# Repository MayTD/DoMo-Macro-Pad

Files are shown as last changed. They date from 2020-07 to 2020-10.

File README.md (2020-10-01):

# DoMo Macro Pad
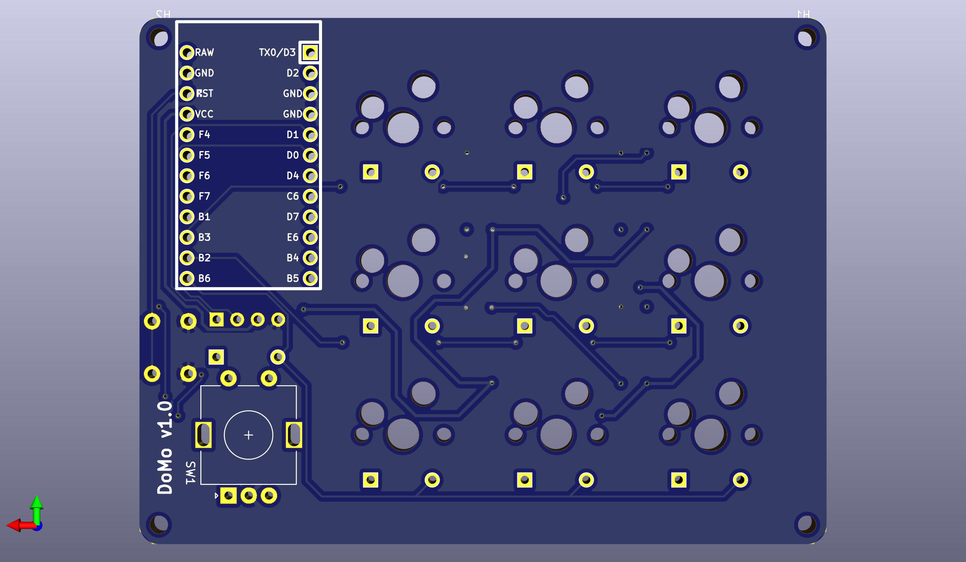
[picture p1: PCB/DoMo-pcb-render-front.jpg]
PCB render

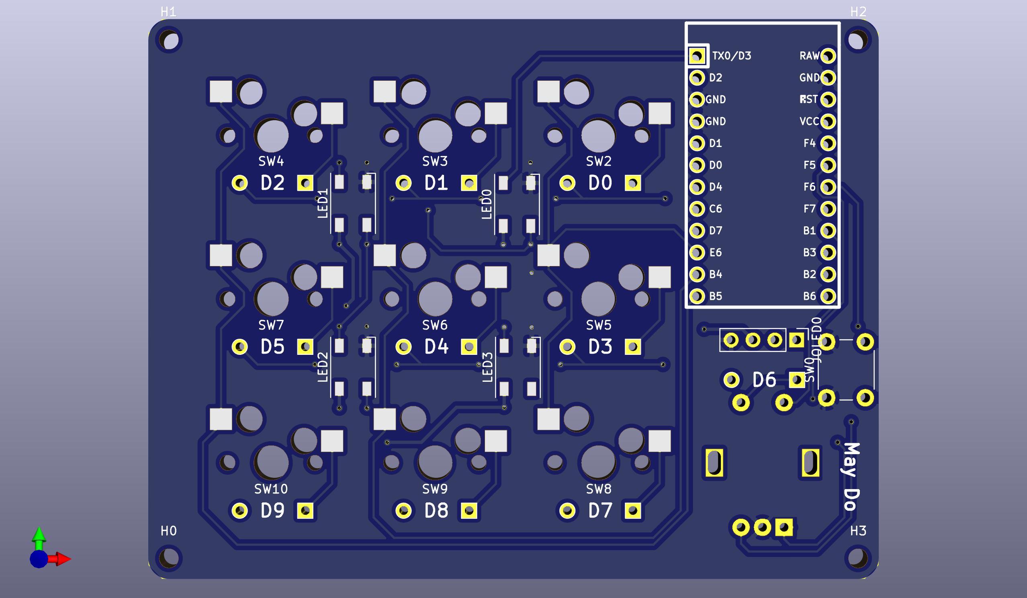
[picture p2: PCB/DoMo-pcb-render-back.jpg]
PCB render


DoMo is a 3x3 macro pad with a rotary encoder and OLED display. It's a straightforward design with a straightforward idea. I originally designed this for myself to provide quick access to most commonly used keys especially for programming. That means the top priority were to include shortcuts for copy and paste! However this can also be used just as any other macro pads for media controls to help improve workflow.

QMK: https://github.com/MayTD/qmk_firmware/tree/master/keyboards/domo

## Features

- QMK Firmware Support
- MX Hot Swap
- OLED Screen
- Rotary Encoder
- LEDS

## Assembly 
Note that source files only covers the PCB. Components must be assembled in order for the board to be functional or completed.
| Number of Parts | Component | Description |
| --- | --- | --- |
| 1 | USB Cable  | Depends on choice of microcontrollers |
| 1 | Pro Micro or Equivalent | Microcontroller that features USB connectivity on-board |
| 1 | Reset Switch | Switch to enter bootloader mode |
| 10 | Diodes | standard switching signal diode | 
| 9 | Kailh MX Sockets | Hot Swapping Sockets which can support MX switches |
| 9 | MX switches | PCB supports PCB Mounted switches | 
| 1 | Rotary Encoder | EC11, 5Pin, 6mm |
| 9 | Keycaps | Any keycaps of choice |
| 1 | Bottom Plate | PCB includes 4 mounting holes that could fit M2 screws | 
| 4 | LEDS | Individual WS2812B 5050 RGB LEDs|
| 4 | 1x4 Connector | 4 pin male header|
| 1 | OLED Display | 0.91 128×32 Display Module|

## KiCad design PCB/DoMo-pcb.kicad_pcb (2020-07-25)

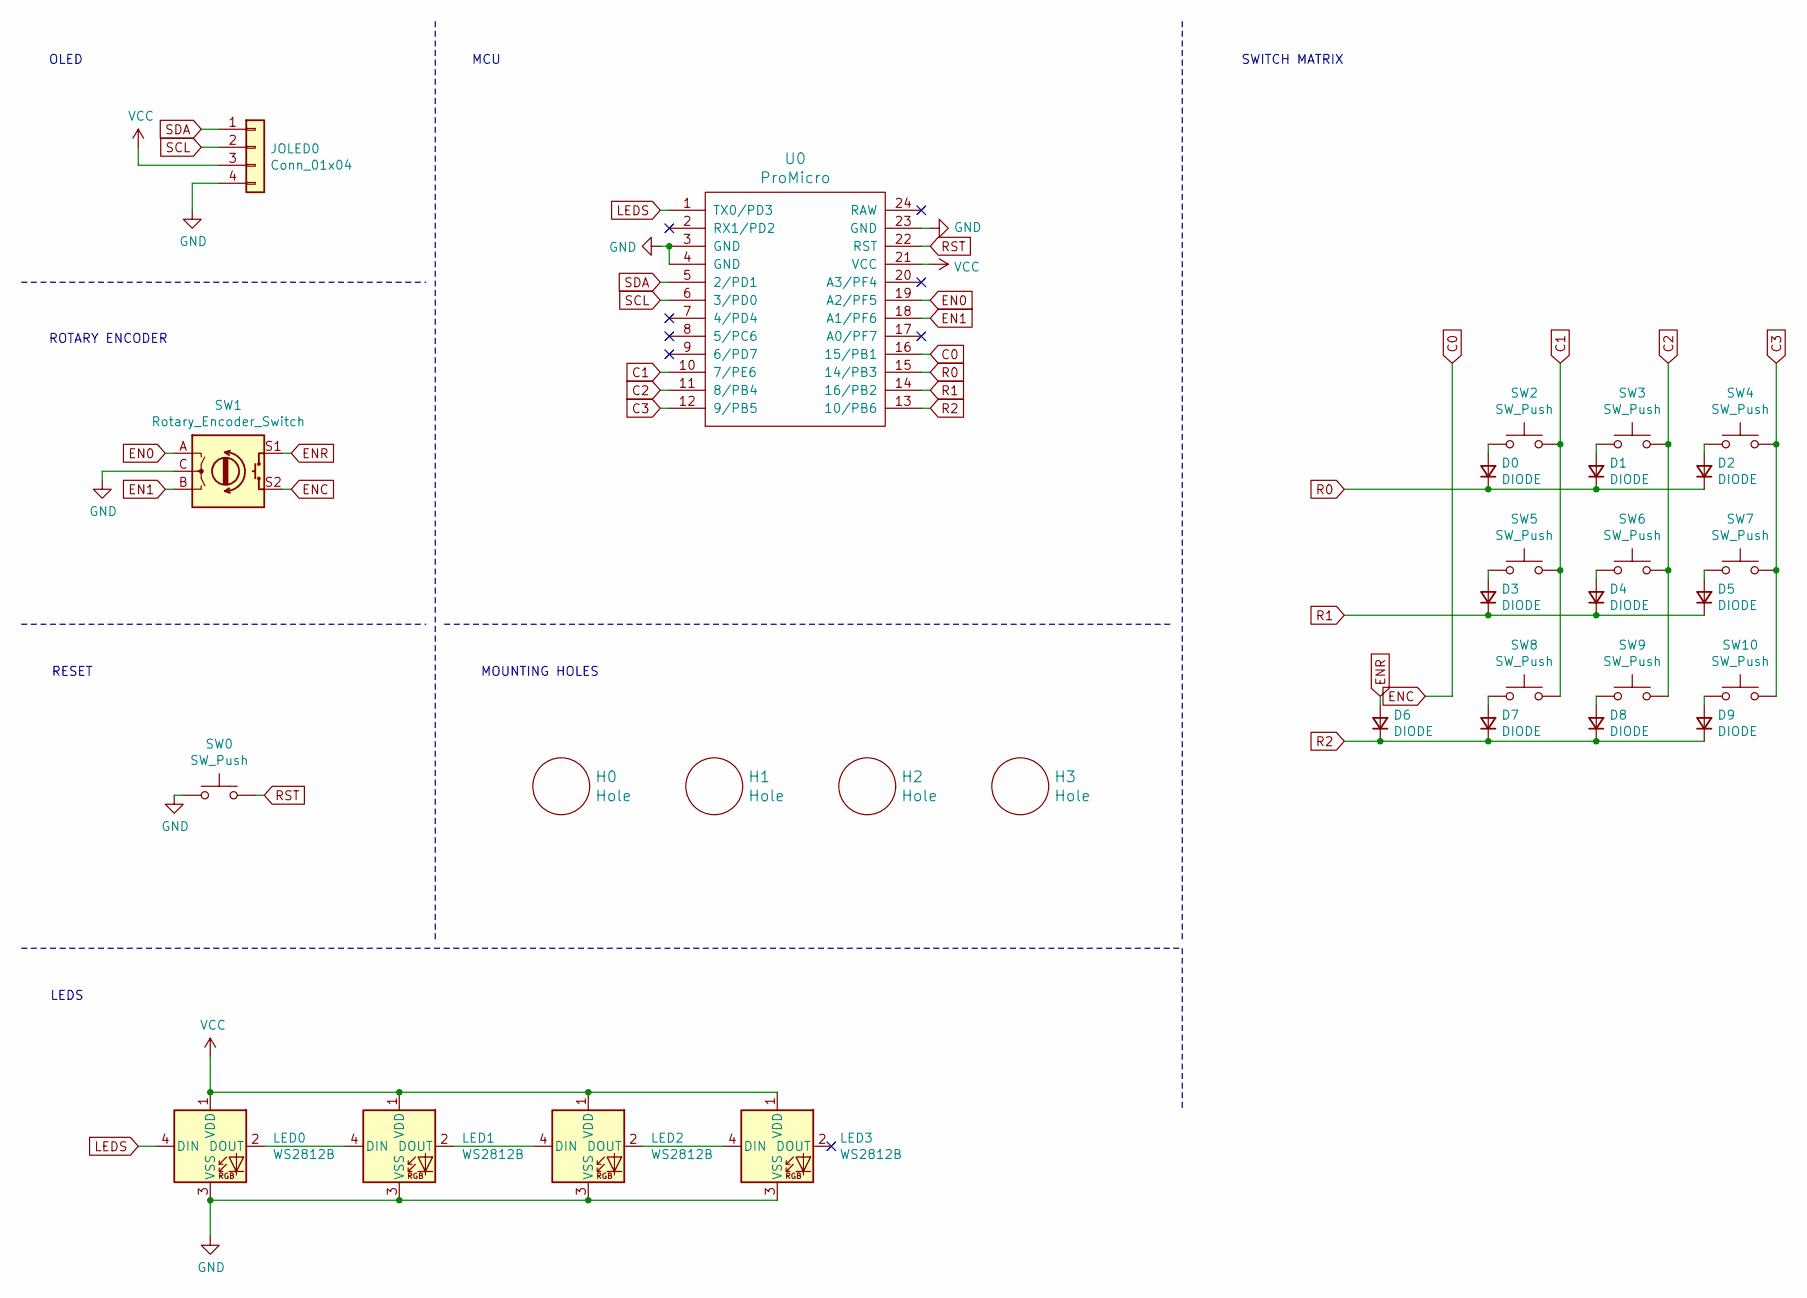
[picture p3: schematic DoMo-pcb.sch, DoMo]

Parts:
D0, D1, D2, D3, D4, D5, D6, D7, D8, D9: DIODE; MD_Diode
H0, H1, H2, H3: Hole; MountingHole_2.2mm_M2
JOLED0: Conn_01x04; Pin_Header_Straight_1x04_Pitch2.54mm
LED0, LED1, LED2, LED3: WS2812B; LED_WS2812B-PLCC4
SW0: SW_Push; SW_PUSH_6mm
SW1: Rotary_Encoder_Switch; RotaryEncoder_Alps_EC11E-Switch_Vertical_H20mm
SW2, SW3, SW4, SW5, SW6, SW7, SW8, SW9, SW10: SW_Push; MXOnly-1U-Hotswap
U0: ProMicro; ArduinoProMicro

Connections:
C0: SW1.S2, U0.16 (15/PB1)
C1: SW2.2, SW5.2, SW8.2, U0.10 (7/PE6)
C2: SW3.2, SW6.2, SW9.2, U0.11 (8/PB4)
C3: SW4.2, SW7.2, SW10.2, U0.12 (9/PB5)
EN0: SW1.A, U0.19 (A2/PF5)
EN1: SW1.B, U0.18 (A1/PF6)
ENR: D6.2 (A), SW1.S1
GND: JOLED0.4, LED0.3 (VSS), LED1.3 (VSS), LED2.3 (VSS), LED3.3 (VSS), SW0.1, SW1.C, U0.3 (GND), U0.4 (GND), U0.23 (GND)
LEDS: LED0.4 (DIN), U0.1 (TX0/PD3)
unnamed: D0.2 (A), SW2.1
unnamed: D1.2 (A), SW3.1
unnamed: D2.2 (A), SW4.1
unnamed: D3.2 (A), SW5.1
unnamed: D4.2 (A), SW6.1
unnamed: D5.2 (A), SW7.1
unnamed: D7.2 (A), SW8.1
unnamed: D8.2 (A), SW9.1
unnamed: D9.2 (A), SW10.1
unnamed: LED0.2 (DOUT), LED1.4 (DIN)
unnamed: LED1.2 (DOUT), LED2.4 (DIN)
unnamed: LED2.2 (DOUT), LED3.4 (DIN)
R0: D0.1 (K), D1.1 (K), D2.1 (K), U0.15 (14/PB3)
R1: D3.1 (K), D4.1 (K), D5.1 (K), U0.14 (16/PB2)
R2: D6.1 (K), D7.1 (K), D8.1 (K), D9.1 (K), U0.13 (10/PB6)
RST: SW0.2, U0.22 (RST)
SCL: JOLED0.2, U0.6 (3/PD0)
SDA: JOLED0.1, U0.5 (2/PD1)
VCC: JOLED0.3, LED0.1 (VDD), LED1.1 (VDD), LED2.1 (VDD), LED3.1 (VDD), U0.21 (VCC)

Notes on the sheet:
OLED
LEDS
ROTARY ENCODER
RESET
SWITCH MATRIX
MCU
MOUNTING HOLES

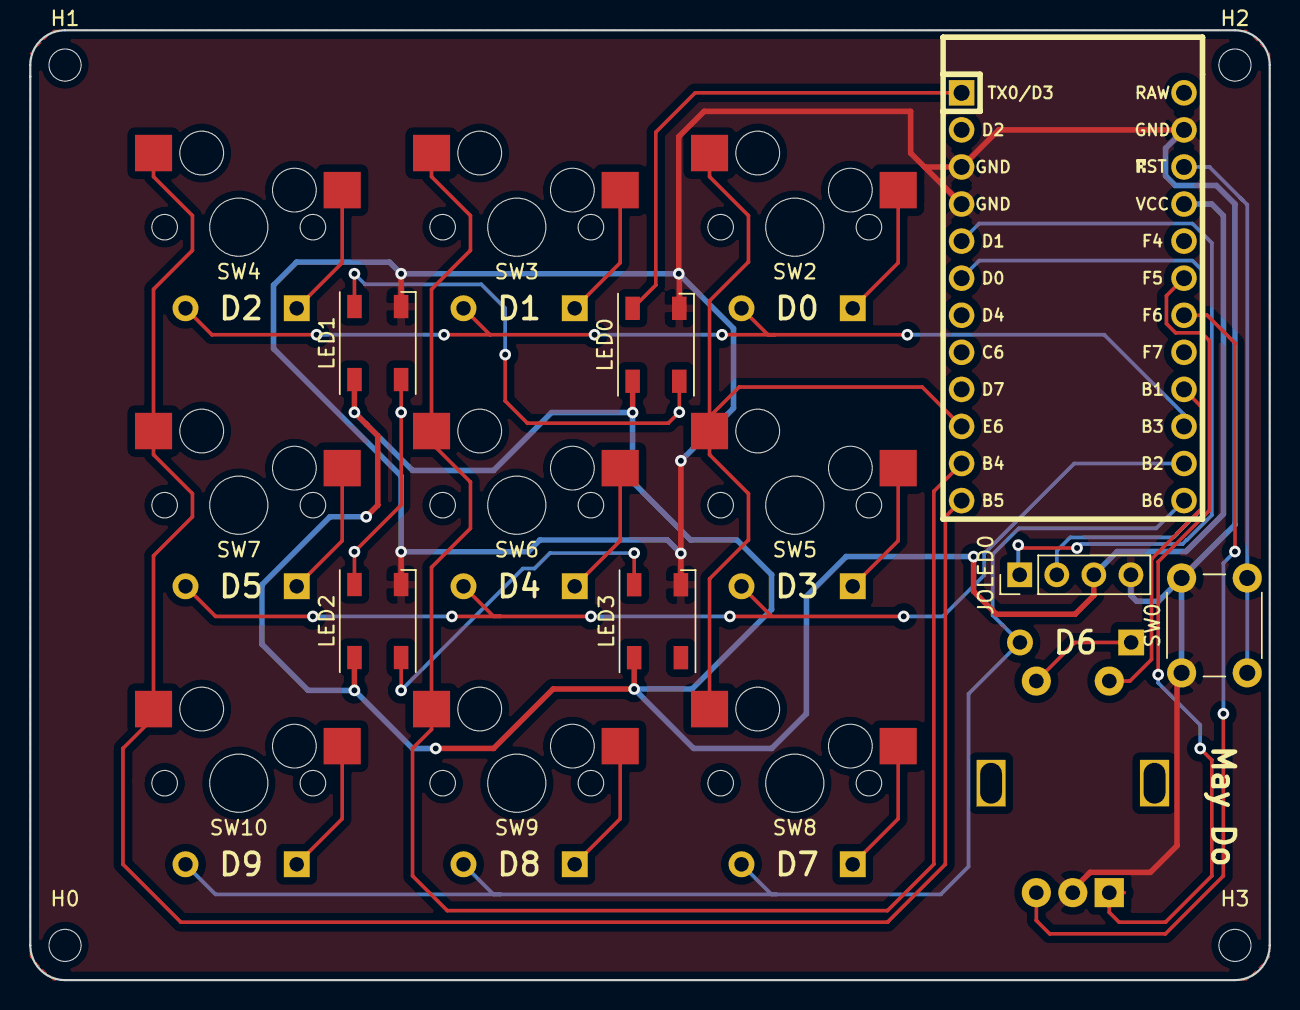
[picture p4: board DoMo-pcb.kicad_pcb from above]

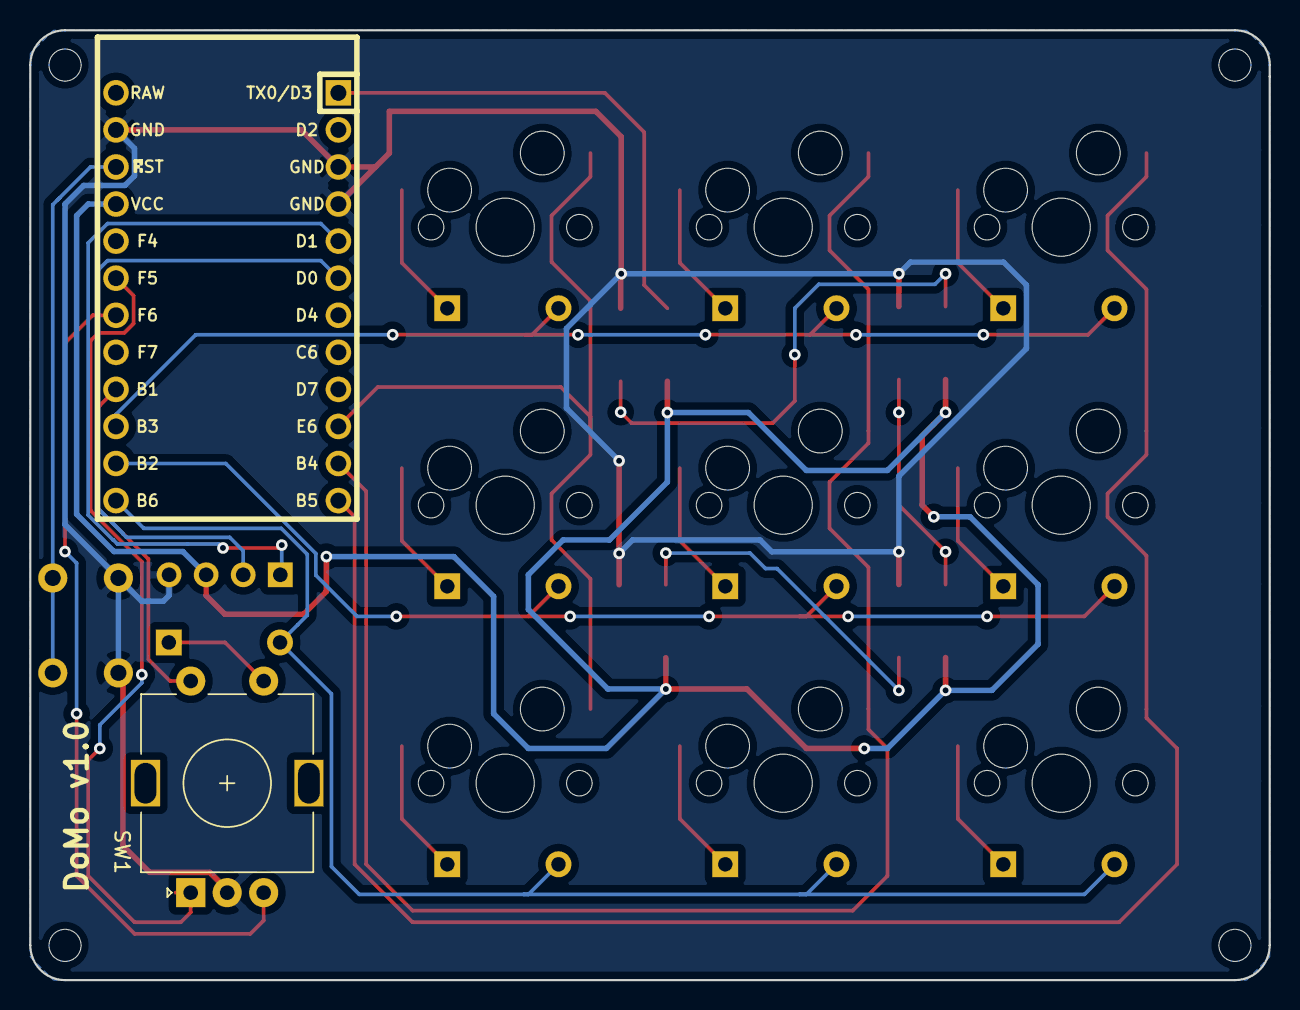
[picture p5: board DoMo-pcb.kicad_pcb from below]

Board: 2 copper layers, 84.9 x 65.1 mm, 31 parts (10 on the bottom side), 28 nets.

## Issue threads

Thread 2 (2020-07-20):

Flip OLEDs 1x4 connector

MayTD, 2020-07-20:
The OLED display would be facing towards the PCB. For reference, the pin holes at the bottom on the display should be ordered as `SDA, SCL, VCC, GND`. This means the PCB should have the pins as the same order. Currently the PCB has the reverse order.

Closed 2020-07-25.

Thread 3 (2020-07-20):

Move Diodes location

MayTD, 2020-07-20:
This is to prevent issues with the diodes interfering with the switch placements. The diodes are directly underneath the switches, so moving it somewhere else (ie. top or side of switch footprint) would be ideal. Alternatively, changing the footprint to support SMD diodes can also fix this issue while keeping the diodes original position.

Closed 2024-09-05.

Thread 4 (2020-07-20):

Change RST button

MayTD, 2020-07-20:
Change the footprint to support a smaller footprint. Possibly a 2 pin button. For reference the current (v1.0) supports 6mm button. This will give more room for other parts, though not necessary.

Closed 2024-09-05.

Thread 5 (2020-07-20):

Move LEDS placement

MayTD, 2020-07-20:
Not necessary, but the LEDS would ideally be more spaces out on the PCB. Currently (v1.0) has all LEDS close to the center.

Closed 2024-09-05.

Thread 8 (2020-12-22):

Question -  quick access to most commonly used keys especially for programming

flight505, 2020-12-22:
Hi May, sorry for creating an "issue" but Git doesn't allow direct messages so it was the only way to ask you a question.
Really cool you made this, I love the idea of having an OLED to play around with some code on. Well, the reason I am writing is that I recently bought a macro board with a large rotary encoder. I just use it for media control and I have a layer set up for adobe illustrator.
Now I was looking for some idea on how to efficiently use it for programming and VScode and then stumbled across your git. I spent some time setting up a layer on my 60% keyboard dedicated to VScode and writing some macros and scripts, the idea was to keep my hands resting on the keyboard while coding/writing and avoid moving to the mouse.
But, I thought there could be some really smart things that could take advantage of the rotary encoder while programming but I haven't found any - if you have discovered some great workflows for programming then please share
Thanks and merry x-mas 🎄

MayTD, 2022-02-08:
@flight505 I use the rotary encoder for volume control but a few suggestions for avoiding the mouse is to use the encoder for scrolling, tab control, or undo/redo. Hope this gives you some ideas!

Closed 2024-09-05.

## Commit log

2020-06-29 init pcb
    [DoMo-pcb.kicad_pcb, DoMo-pcb.sch]
2020-06-29 remove subfolder
    [DoMo-pcb.kicad_pcb, DoMo-pcb.sch]
2020-06-30 add footprints and symbol libs
2020-07-03 init mcu
    [DoMo-pcb.sch]
2020-07-03 create decoupling capacitors
    [DoMo-pcb.sch]
2020-07-04 create rotary encoder
    [DoMo-pcb.sch]
2020-07-04 create OLED pins
    [DoMo-pcb.sch]
2020-07-04 change mcu to pro micro
    [DoMo-pcb.sch]
2020-07-04 create LEDS
    [DoMo-pcb.sch]
2020-07-05 create matrix
    [DoMo-pcb.sch]
2020-07-05 add mx/alps footprint
2020-07-05 update footprints fields
    [DoMo-pcb.sch]
2020-07-06 pcb layout
    [DoMo-pcb.sch]
2020-07-07 remove 1 led and wire up oled/rotary
    [DoMo-pcb.kicad_pcb, DoMo-pcb.sch]
2020-07-07 rotary and oled wired up
    [DoMo-pcb.kicad_pcb]
2020-07-07 wire up col and row
    [DoMo-pcb.kicad_pcb]
2020-07-07 wire up leds
    [DoMo-pcb.kicad_pcb]
2020-07-08 remove unconnected routes
    [DoMo-pcb.kicad_pcb]
2020-07-09 ground fill
    [DoMo-pcb.kicad_pcb]
2020-07-09 render 3d pcb
2020-07-09 creat Gerbers
    [DoMo-pcb-B_Cu.gbl, DoMo-pcb-B_Mask.gbs, DoMo-pcb-B_SilkS.gbo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]
2020-07-10 fix edges
    [DoMo-pcb.kicad_pcb]
2020-07-10 add dimensions
    [DoMo-pcb.kicad_pcb]
2020-07-10 update Gerbers
    [DoMo-pcb-B_Cu.gbl, DoMo-pcb-B_Mask.gbs, DoMo-pcb-B_SilkS.gbo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]
2020-07-10 Update assembly readme
2020-07-10 Add Diodes to requirements
2020-07-10 fix number of diodes
2020-07-25 fix 1x4 connector
    [DoMo-pcb.kicad_pcb]
2020-07-25 regenerate gerber for connector fix
    [DoMo-pcb-B_Cu.gbl, DoMo-pcb-B_Mask.gbs, DoMo-pcb-B_SilkS.gbo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]
